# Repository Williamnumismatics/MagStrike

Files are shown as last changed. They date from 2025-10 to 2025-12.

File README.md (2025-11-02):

# MagStrike

MagStrike is a custom hall effect keyboard that has a 60 percent layout.
It uses the Gateron Low Profile Magnetic Jade Switches. The brains of this keyboard is a Rpi Pico 2 that runs micropython that communicates with a python script running on the main PC/Laptop

## Why did i build this???
I built this keyboard because i have always wanted to make my own keyboard from scratch and when i stumbled across hall-effect one day i quickly fell in love with it. I also wanted to use low profile switches so my wrists wouldnt hurt all day. I Found the perfect switch for this which is the Gateron Low Profile Magnetic Jade switches.

## What did it take?
It took about 2 weeks to build this it is my first every PCB and unfortunately i couldn't find anywhere to place the rasberry pi pico so i had to put it outside the keyboard. I also designed the case without a top plate so it is easy to print and easy to see the insides

## If i did it again what would i do?
 I would probably make a custom devboard with the rp2040 and embed it inside the footprint of the keyboard.
 
## READ THIS:
the 3d file was to big to commit to github so this is the google drive link:
    https://drive.google.com/file/d/1xGtgr9WMyzFMHPNl8FSLAcrnGV7yFdcr/view
 
### My Bill of Materials

| Item | Description | Quantity | Unit Price (USD) | Total Price (USD) | Shipping(USD) | URL | Running Total(USD) |
| :--- | :--- | :--- | :--- | :--- | :--- | :--- | :--- |
| Switches | Gateron Low Profile Magnetic Jade | 1 x pack of 70 | 56 | 56 | 4.3 | [Link](https://www.gateron.com/products/gateron-low-profile-magnetic-jade-switch?VariantsId=10872) | 60.3 |
| Stabilizer | GATERON Low Profile Plate Mounted Stabilizer | 1 | 8 | 8 | 2.45(Processing Fee) | [Link](https://www.gateron.com/products/gateron-low-profile-plate-mounted-stabilizer?VariantsId=10540) | 70.75 |
| Capacitor | 50V 100nF X7R ±10% 0603 Ceramic Capacitors RoHS | 100 | 0.0025 | 0.25 | 8.87 | [Link](https://www.lcsc.com/product-detail/C14663.html?utm_source=chatgpt.com) | 79.87 |
| Hall Effect Sensor | Analog-Bipolar Hall Effect Sensor | 70 | 0.2345 | 16.42 | N/A | [Link](https://www.lcsc.com/product-detail/C962159.html) | 96.29 |
| Multiplexer | IC MUX 16:1 160OHM 24SOIC | 5 | 0.83 | 3.32 | N/A | [Link](https://www.lcsc.com/sea rch?q=%20CD74HC4067M96%20&s_z=n_%20CD74HC4067M96%20) | 99.61 |
| Rasberry Pi Pico | Rasberry Pi Pico | 1 | 4.32 | 4.32 | 2.42 | [Link](https://core-electronics.com.au/raspberry-pi-pico.html) | 106.35 |
| PCB | THE pcb | 5 | N/A | 26.35 | 18.43 | [Link](https://cart.jlcpcb.com/shopcart/cart/) | 151.13 |

### I didnt include all of the shopping carts so here it is(Note that on gateron website it says some cheaper that the bom but that is cause of a sale that is ending in 16 hours.):
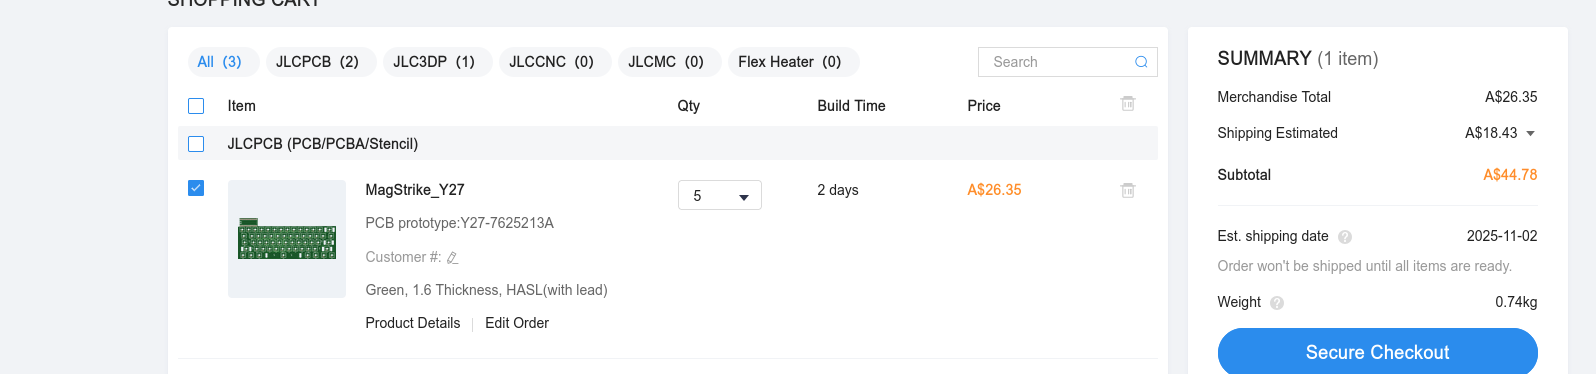
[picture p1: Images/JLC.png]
PCB

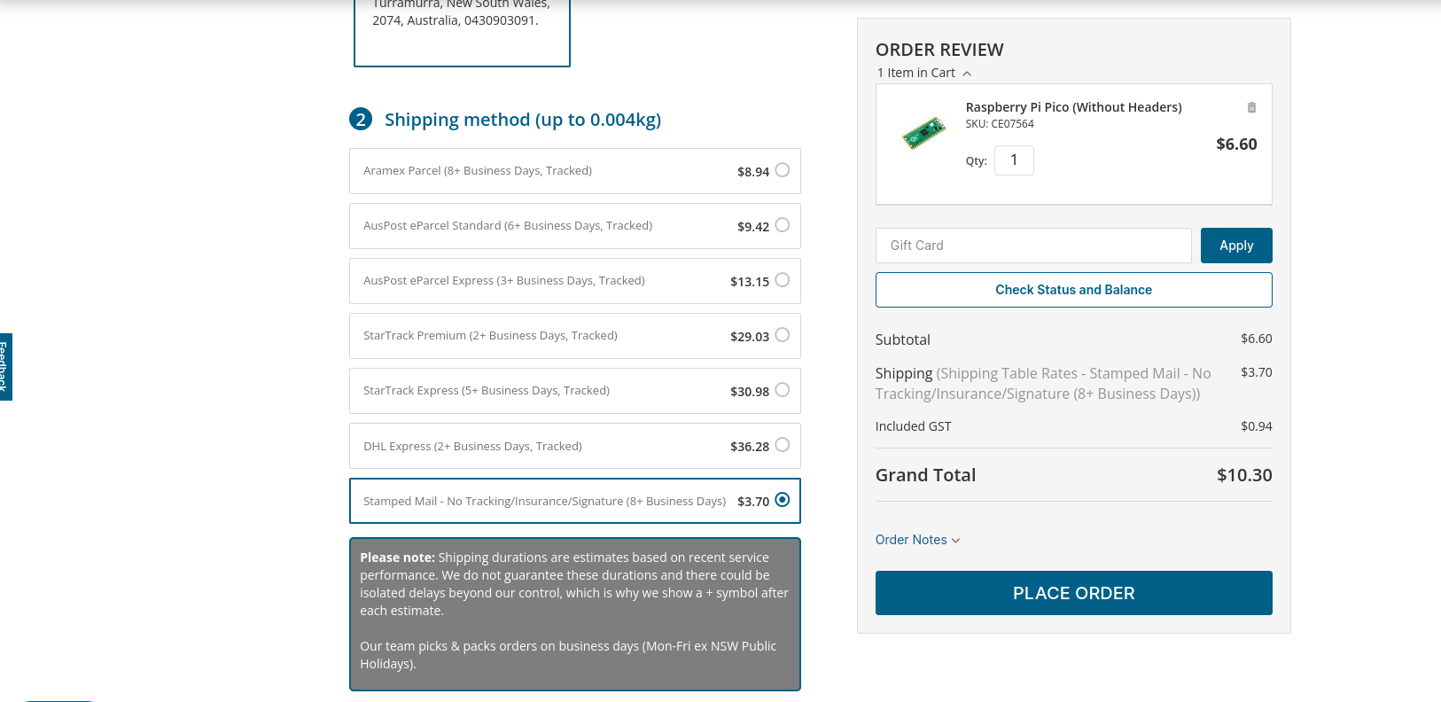
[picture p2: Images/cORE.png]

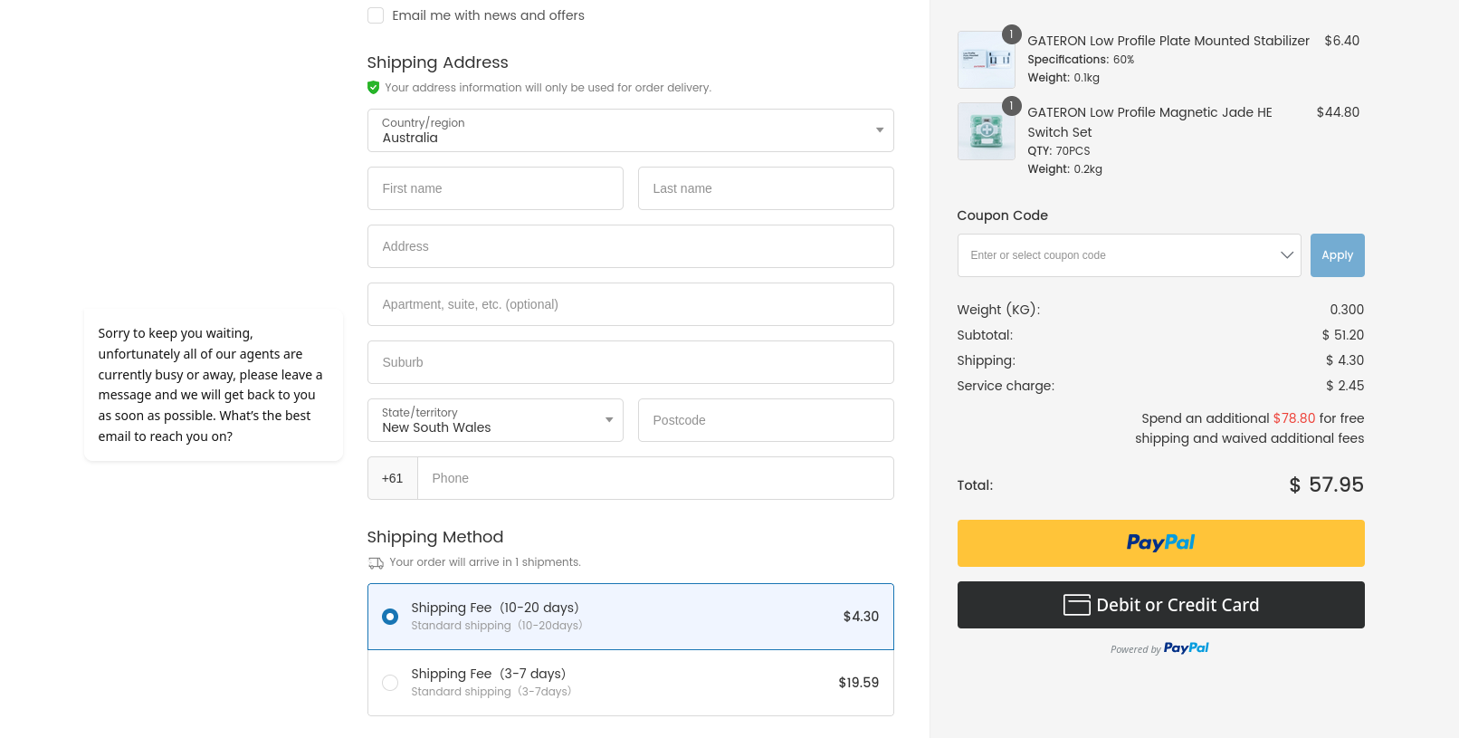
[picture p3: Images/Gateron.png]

shop
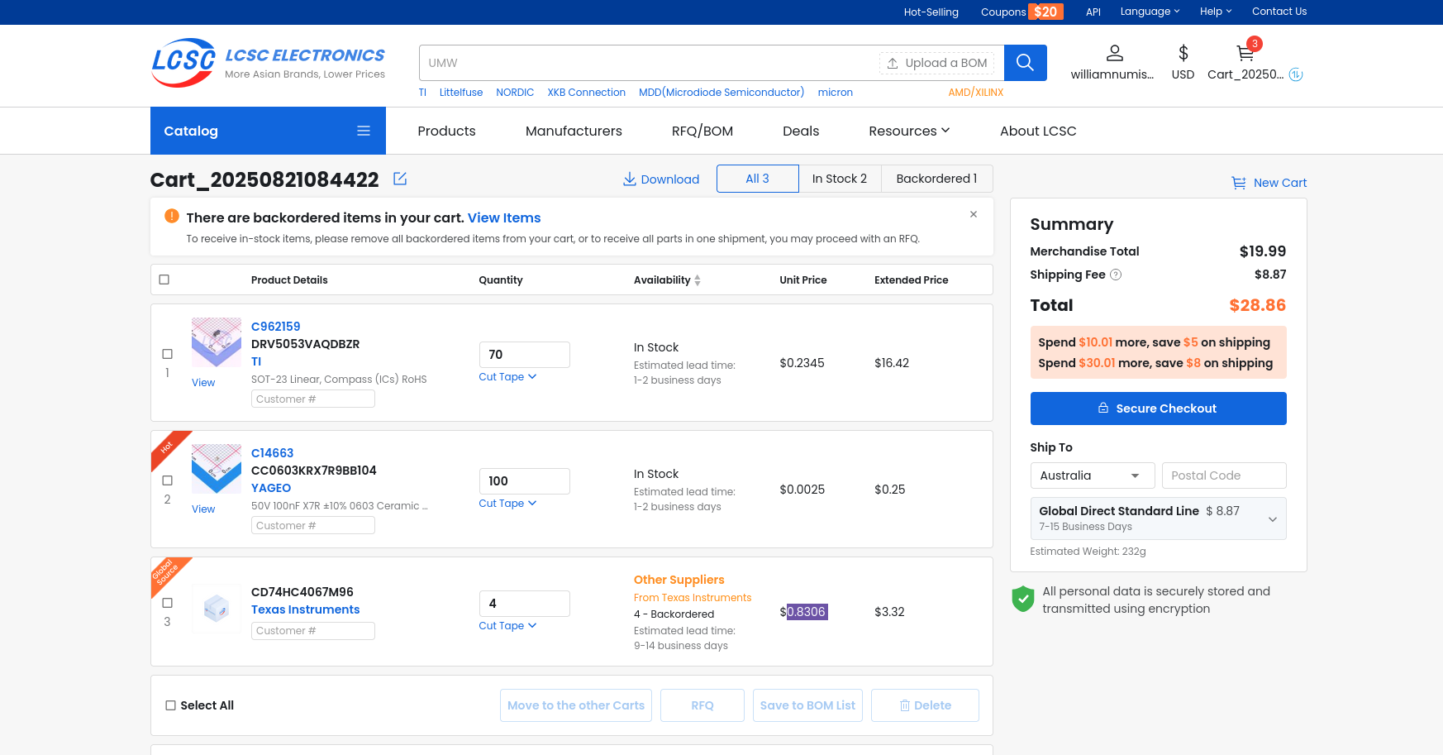
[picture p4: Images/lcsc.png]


# 3d render:
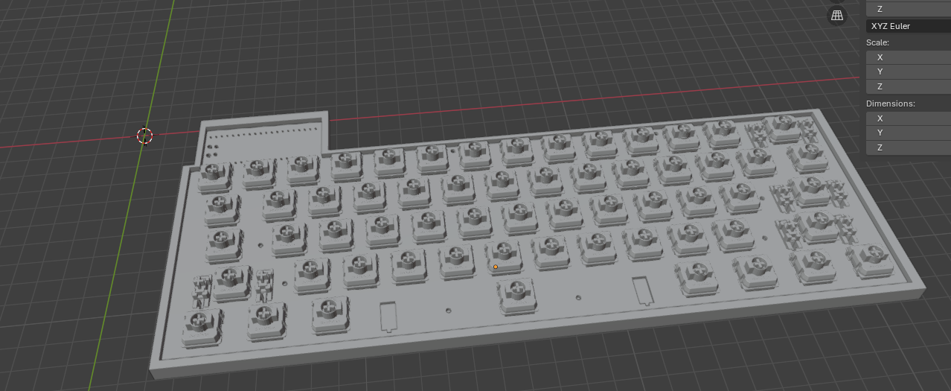
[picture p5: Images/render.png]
Render


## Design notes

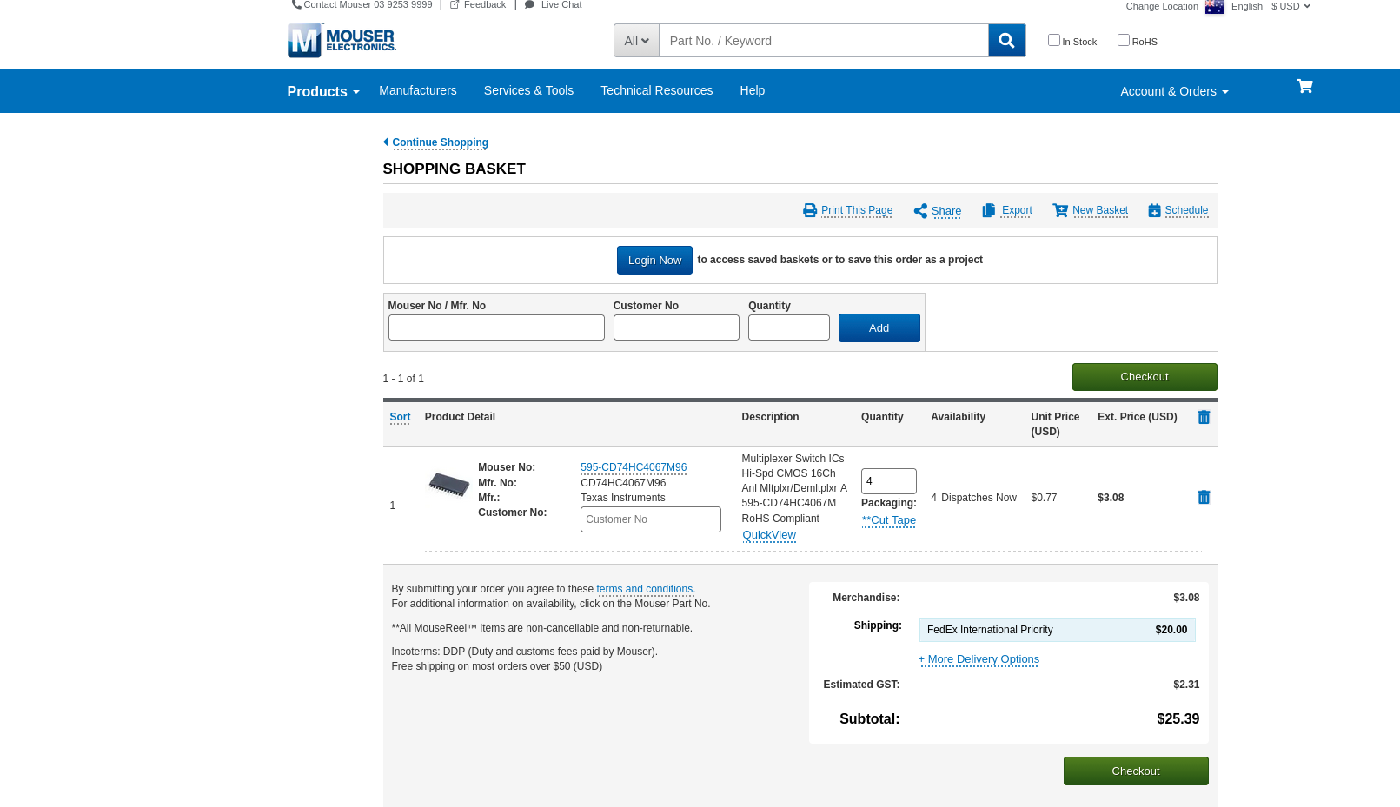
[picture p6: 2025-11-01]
Images/Mouser.png

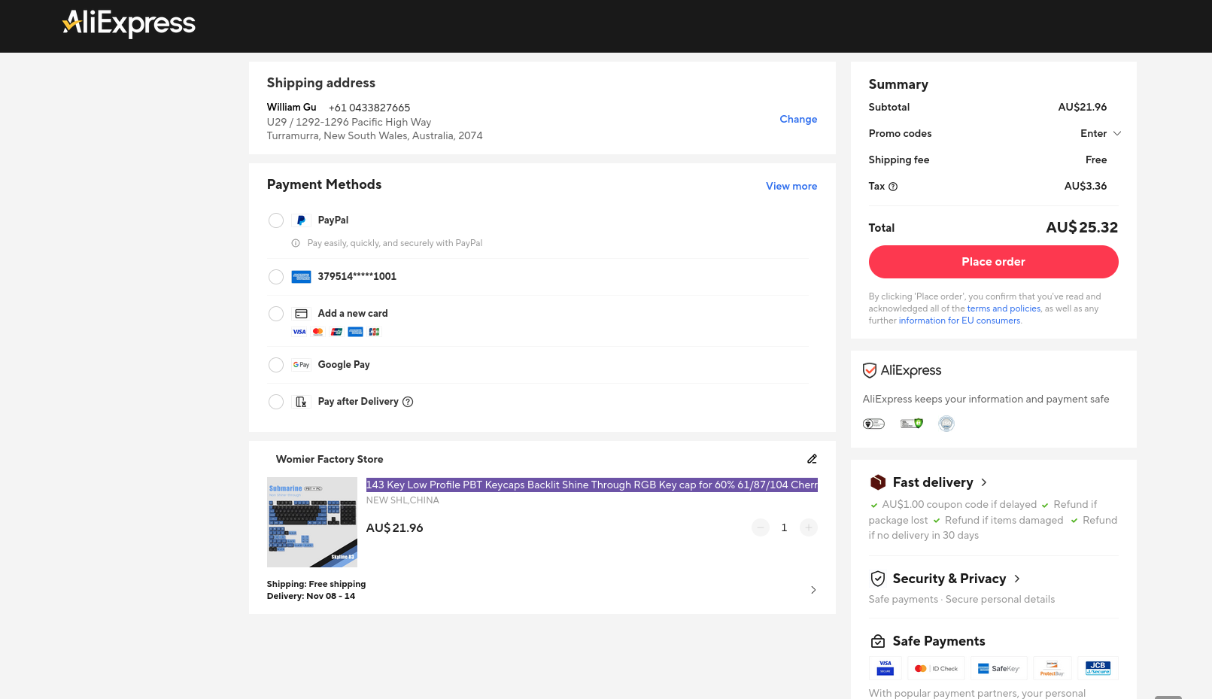
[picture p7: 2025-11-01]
Images/Ali.png

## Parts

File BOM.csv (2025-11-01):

Item | Description | Quantity | Unit Price (USD) | Total Price (USD) | Shipping(USD) | URL | Running Total(USD)
Switches | Gateron Low Profile Magnetic Jade | 1 x pack of 70 | 56 | 56 | 4.3 | https://www.gateron.com/products/gateron-low-profile-magnetic-jade-switch?VariantsId=10872 | 60.3
Stabilizer | GATERON Low Profile Plate Mounted Stabilizer | 1 | 8 | 8 | 2.45(Processing Fee) | https://www.gateron.com/products/gateron-low-profile-plate-mounted-stabilizer?VariantsId=10540 | 70.75
Capacitor | 50V 100nF X7R ±10% 0603 Ceramic Capacitors RoHS | 100 | 0.0025 | 0.25 | 8.87 | https://www.lcsc.com/product-detail/C14663.html?utm_source=chatgpt.com | 79.87
Hall Effect Sensor | Analog-Bipolar Hall Effect Sensor | 70 | 0.2345 | 16.42 | N/A | https://www.lcsc.com/product-detail/C962159.html | 96.29
Multiplexer | IC MUX 16:1 160OHM 24SOIC | 5 | 0.83 | 3.32 | N/A | https://www.lcsc.com/search?q=%2520CD74HC4067M96%2520&s_z=n_%2520CD74HC4067M96%2520 | 99.61
Rasberry Pi Pico | Rasberry Pi Pico | 1 | 4.32 | 4.32 | 2.42 | https://core-electronics.com.au/raspberry-pi-pico.html | 106.35
PCB | THE pcb | 5 | N/A | 26.35 | 18.43 | https://cart.jlcpcb.com/shopcart/cart/ | 151.13

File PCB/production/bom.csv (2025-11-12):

Designator | Footprint | Quantity | Value | LCSC Part #
A1 | RaspberryPi_Pico_Common_Unspecified | 1 | RaspberryPi_Pico
SW1, SW10, SW11, SW12, SW13, SW14, SW15, SW16, SW17, SW18, SW19, SW2, SW20, SW21, SW22, SW23, SW24, SW25, SW26, SW27, SW28, SW29, SW3, SW30, SW31, SW32, SW33, SW34, SW35, SW36, SW37, SW38, SW39, SW4, SW40, SW41, SW42, SW43, SW44, SW45, SW46, SW47, SW48, SW49, SW5, SW50, SW51, SW52, SW53, SW54, SW55, SW56, SW57, SW58, SW59, SW6, SW60, SW61, SW7, SW8, SW9 | Gateron_Low_Profile_Magnetic_Jade | 61 | ~
U1, U2, U3, U4 | SOIC-24W_7.5x15.4mm_P1.27mm | 4 | CD74HC4067M

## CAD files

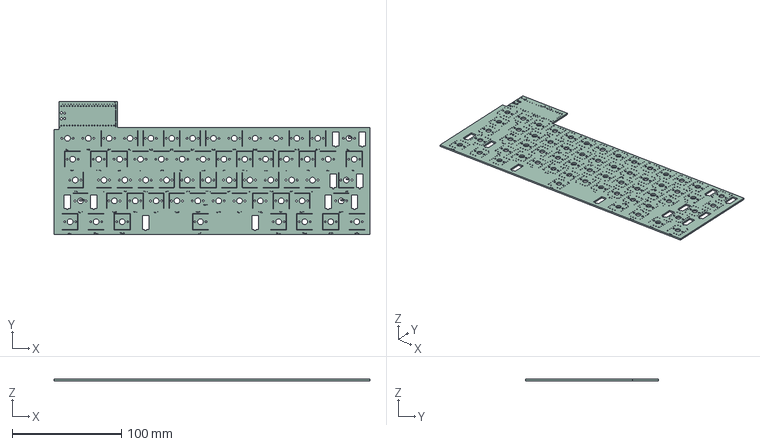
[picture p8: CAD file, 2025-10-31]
PCB/MagStrike.step
288.7 x 121.5 x 1.66 mm
MagStrike_silkscreen x 2
MagStrike_PCB

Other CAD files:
SWITCH.blend
print.blend

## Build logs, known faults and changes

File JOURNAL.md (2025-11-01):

<!--
  ===================    !!READ THIS NOTICE!!   ====================
  DO NOT edit this file manually. Your changes WILL BE OVERWRITTEN!
  This journal is auto generated and updated by Hack Club Blueprint.
  To edit this file, please edit your journal entries on Blueprint.
  ==================================================================
-->

## 10/23/2025 7 PM - Starteds on the thing and also started on the footprint  

First i started by creating the BOM and the plan file then i started on the footprint since i couldnt find any available footprint for my gateron low profile magnetic jade switch, i decided to make my own i have just done puting the sensor unter the place on the footprint next im going to move to the symbol and filling in the BOM


## 10/23/2025 8 PM - Finished Footprint  

Finished footprint for the magnetic switch was going to put per key rgb but then figured to complex as that would exeed the amp rating of the pico which would force me to use a usb PD breakotu board. Now going to do the symbol for it and then i will start on the schematic


## 10/23/2025 9 PM - doing the schematic  

finished symbol and Started doing the schematics added 61 switches 4 multiplexers and the rasberry pi pico next wil finish and then move on to pcb stuff.


## 10/24/2025 - near finish shematic  

Finished with footprint and symbol fot the switch now doingthe shematic currently wiring the 61 switches up to some analog multiplexers that go into a rasberry pi pico 


## 10/29/2025 8 PM - Finished Schematic  

Took a break and how have finished schematic will move onto the footprint next i wish myself good luck and i hope everything will turn out alright :))

## 10/29/2025 9 PM - Fixed ERC  

Ran ERC and fixed problem of the adc_vref not connecting to anything it is fixed now so tommorow i am going to move onto doing the footprints and acual pcb should be ready in about a week :)
warnings are just extra pins
 

## 10/30/2025 7 PM - Did stabilizer things  

CReated footprints for my stabilizer because i couldnt find them anywhere spent a good 30 minutes trying tho they are the gateron low profile stabilizers.

## 10/30/2025 8 PM - Started PCB  

Started PCB but ran into a problem where two components in a singular footprint was too close. Had to restart i just finished routing key 14 out of 61.

## 10/31/2025 10 AM - nearly there  

Finished Routing the switches and wil now wire up all the pins for the multiplexers. after that will work on mob and some software. Then i will ship for the first time :)Screenshot 2025-10-31 at 10.36.49 am

## 10/31/2025 2 PM - 99% done with PCB  

fINALLY FINISHED PCB ! now all i need to do i the edge cut the bom and the readme so exited to see this project come to life now !!!!!!!!! Will try finish by the end of next week :)

Screenshot 2025-10-31 at 10.36.55 am

## 10/31/2025 3 PM - Done with the PCB  

fINISHED the edge cuts but i need to put the stabilizers in but those footprints are on my PC so rn i have done everything. Wehn i get home ima gonna do the readme and bom.
Screenshot 2025-10-31 at 3.03.08 pm

## 10/31/2025 5 PM - Finished PCB :)  

Finished PCB will now write the BOM and also the readme :) Hopefully it will get approved soon. Will then do hand soldering with heatgun and also solder paste

## 10/31/2025 9 PM - Done README and BOM  

Finished Bom and README :) will ship it for review and if there is anything i can do to change, i will change. Dear Reviewer: Thanks for looking at my project :) Hope its good

## 11/1/2025 10 AM - Ok did the code  

BTW IMPOORTANT::: THIS CODE IS VIBE CODED i think it is allowed but if it isnt please ban me cause i know that it is vibe coded cause in the docs it didnt say i couldnt vibe code the firmware. ChatGPT is goated:)


## 11/1/2025 11 AM - cHANGED the BOM  

I changed the BOM and also changed the readme cause i realised in the bom my multiplexer was out of stock in LCSC so i switched to Mouser. I also relised that the price was off now and also i didnt put screenshots of my other shopping carts everything is in the README. 

### Reviewer Please Check the README!!!

## 11/1/2025 3 PM - Changed some stuff  

Reviewer said i have to cost optimize my thing so i removed the keycaps so i will 3d print them mysel;f and also changed the multiplexers from mouser to lcsc to avoid shipping.

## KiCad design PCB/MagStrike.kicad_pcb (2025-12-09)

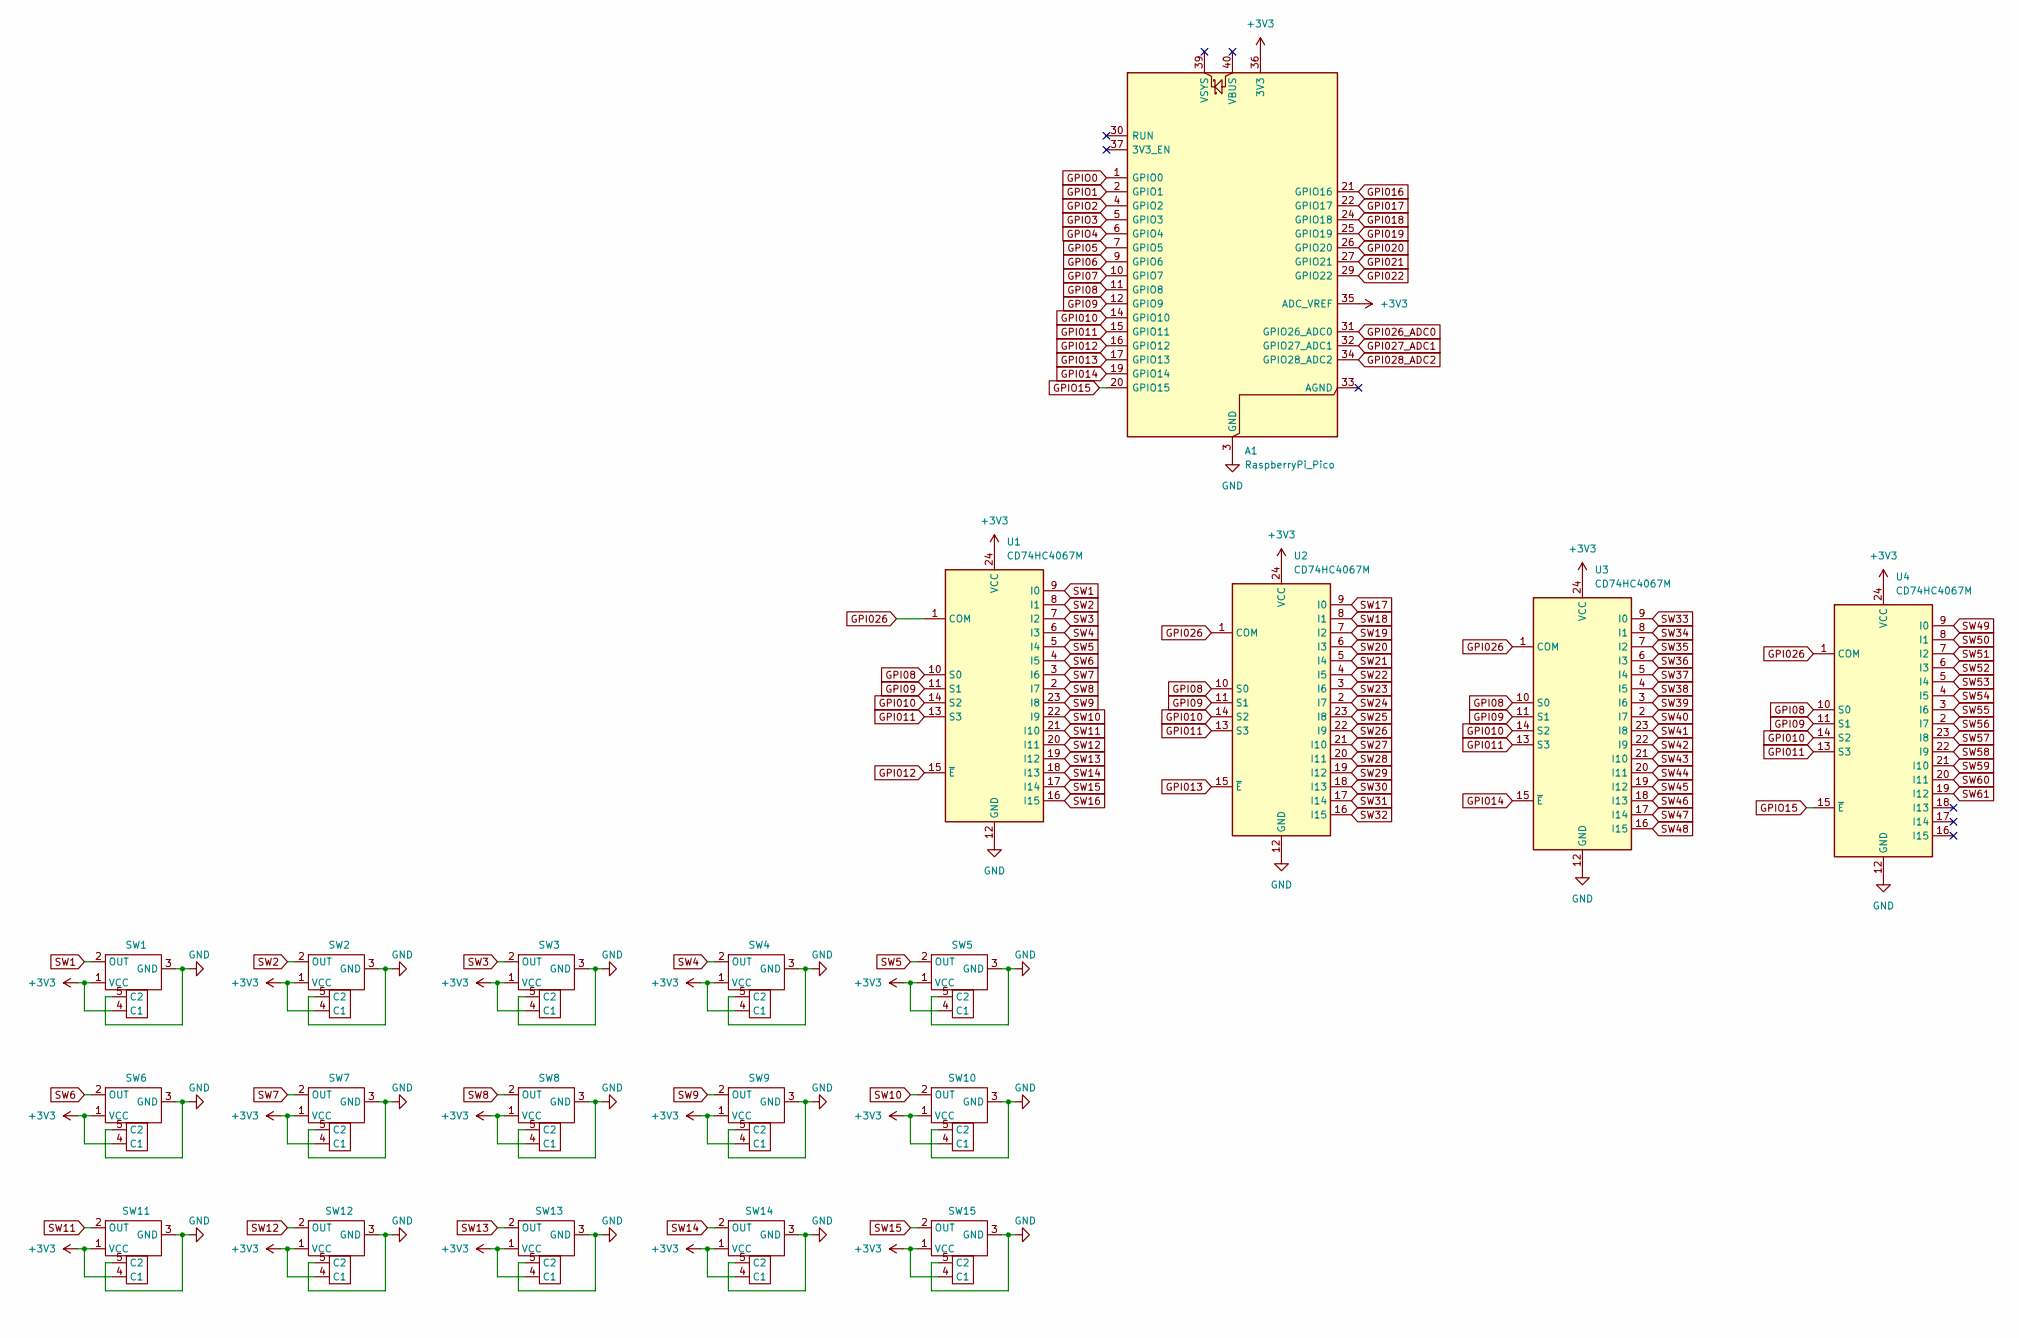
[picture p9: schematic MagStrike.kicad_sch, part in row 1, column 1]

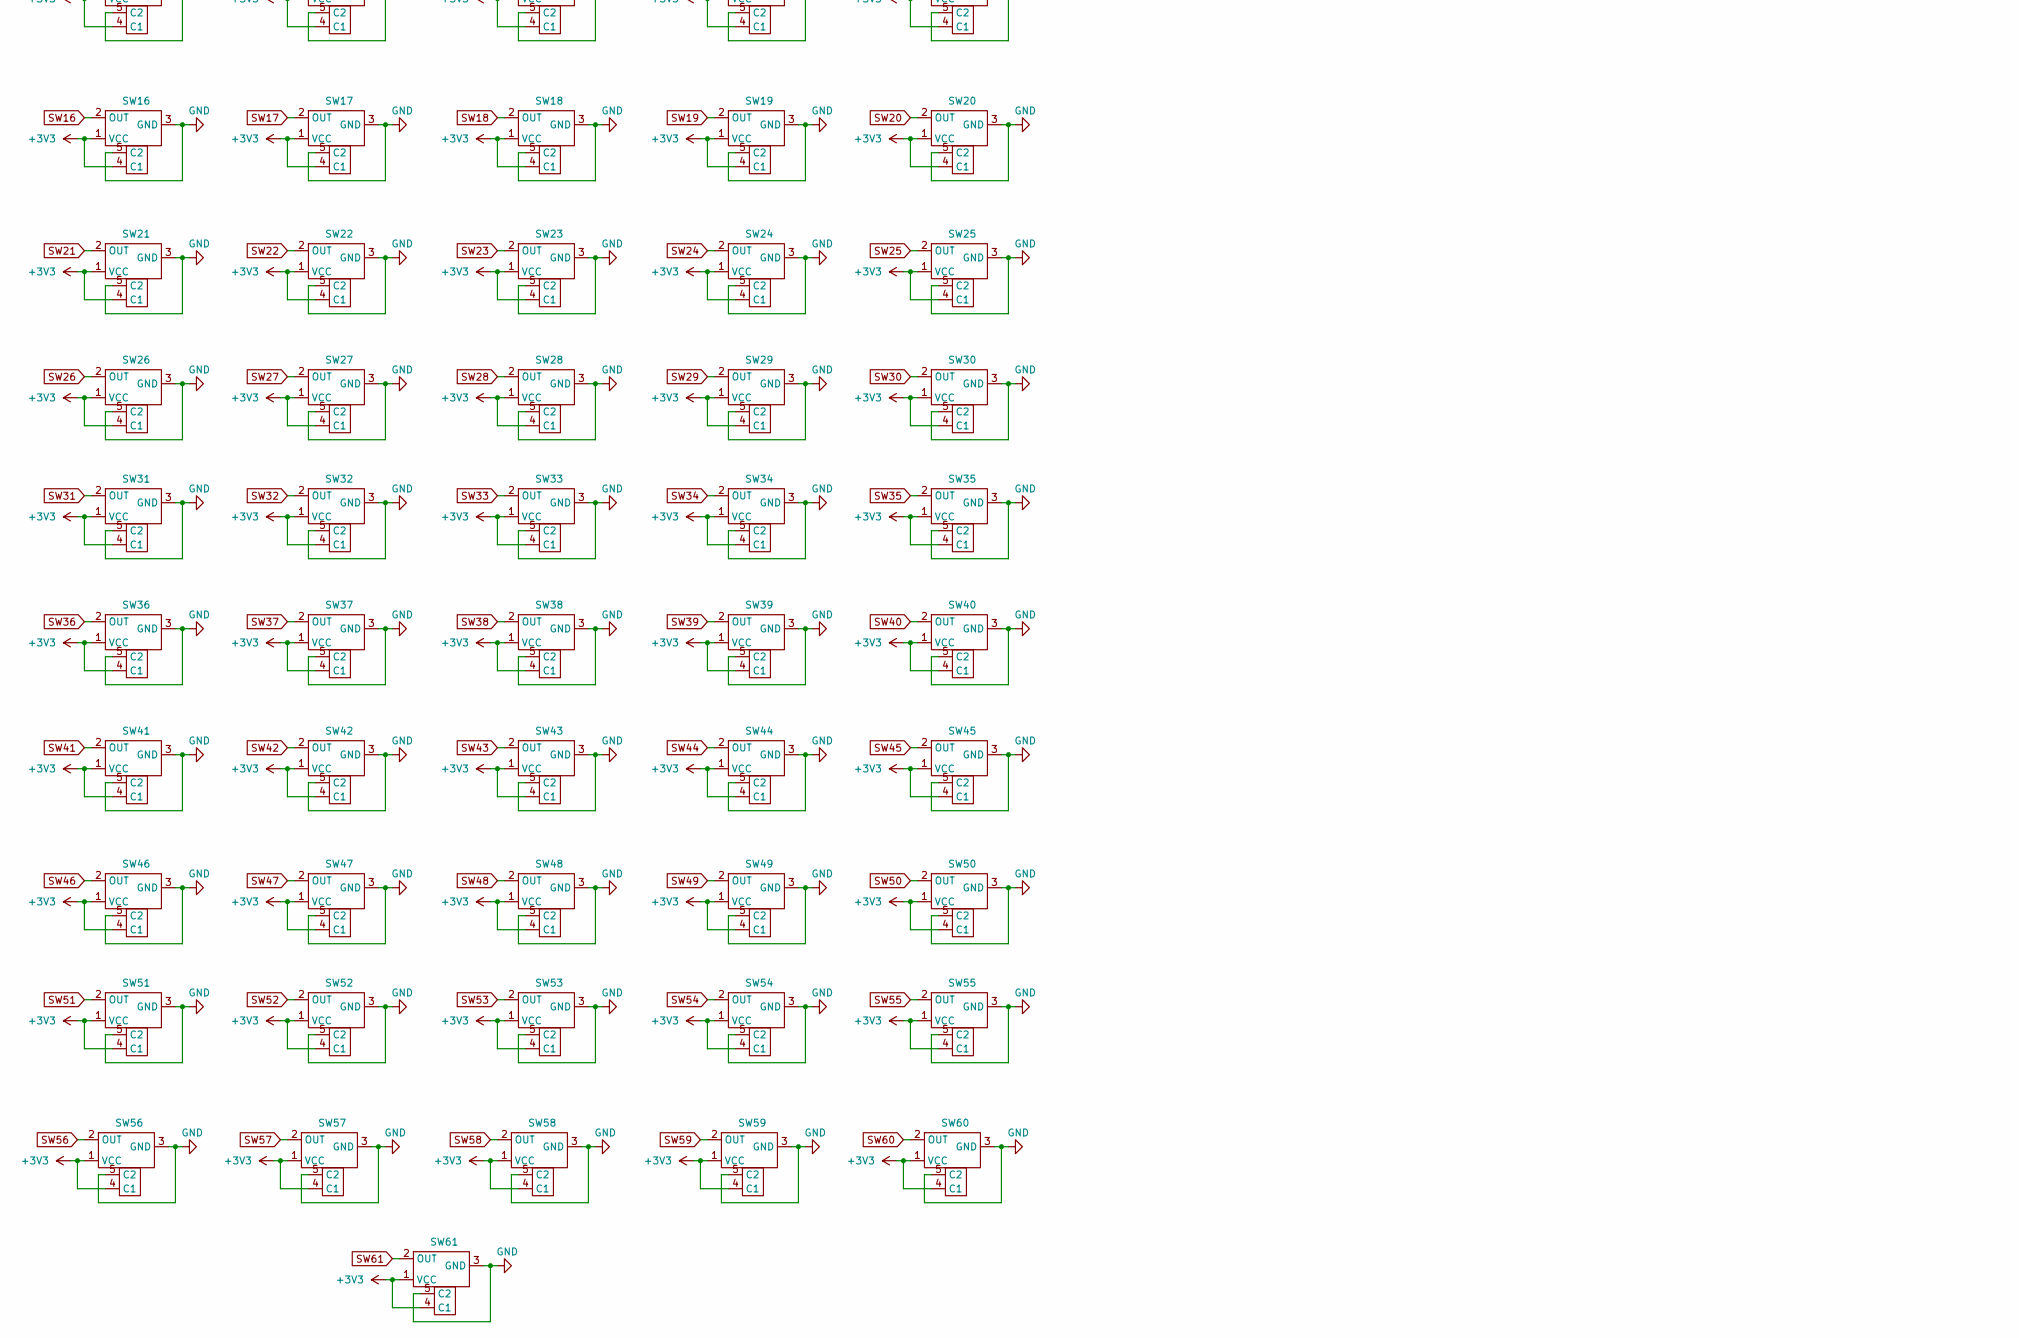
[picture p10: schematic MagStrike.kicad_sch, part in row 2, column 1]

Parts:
A1: RaspberryPi_Pico; RaspberryPi_Pico_Common_Unspecified
SW1, SW2, SW3, SW4, SW5, SW6, SW7, SW8, SW9, SW10, SW11, SW12, SW13, SW14, SW15, SW16, SW17, SW18, SW19, SW20, SW21, SW22, SW23, SW24, SW25, SW26, SW27, SW28, SW29, SW30, SW31, SW32, SW33, SW34, SW35, SW36, SW37, SW38, SW39, SW40, SW41, SW42, SW43, SW44, SW45, SW46, SW47, SW48, SW49, SW50, SW51, SW52, SW53, SW54, SW55, SW56, SW57, SW58, SW59, SW60, SW61: Gateron_Low_Profile_Magnetic_Jade
U1, U2, U3, U4: CD74HC4067M; SOIC-24W_7.5x15.4mm_P1.27mm

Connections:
+3V3: A1.35 (ADC_VREF), A1.36 (3V3), SW1.1 (VCC), SW1.4 (C1), SW2.1 (VCC), SW2.4 (C1), SW3.1 (VCC), SW3.4 (C1), SW4.1 (VCC), SW4.4 (C1), SW5.1 (VCC), SW5.4 (C1), SW6.1 (VCC), SW6.4 (C1), SW7.1 (VCC), SW7.4 (C1), SW8.1 (VCC), SW8.4 (C1), SW9.1 (VCC), SW9.4 (C1), SW10.1 (VCC), SW10.4 (C1), SW11.1 (VCC), SW11.4 (C1), SW12.1 (VCC), SW12.4 (C1), SW13.1 (VCC), SW13.4 (C1), SW14.1 (VCC), SW14.4 (C1), SW15.1 (VCC), SW15.4 (C1), SW16.1 (VCC), SW16.4 (C1), SW17.1 (VCC), SW17.4 (C1), SW18.1 (VCC), SW18.4 (C1), SW19.1 (VCC), SW19.4 (C1), SW20.1 (VCC), SW20.4 (C1), SW21.1 (VCC), SW21.4 (C1), SW22.1 (VCC), SW22.4 (C1), SW23.1 (VCC), SW23.4 (C1), SW24.1 (VCC), SW24.4 (C1), SW25.1 (VCC), SW25.4 (C1), SW26.1 (VCC), SW26.4 (C1), SW27.1 (VCC), SW27.4 (C1), SW28.1 (VCC), SW28.4 (C1), SW29.1 (VCC), SW29.4 (C1), SW30.1 (VCC), SW30.4 (C1), SW31.1 (VCC), SW31.4 (C1), SW32.1 (VCC), SW32.4 (C1), SW33.1 (VCC), SW33.4 (C1), SW34.1 (VCC), SW34.4 (C1), SW35.1 (VCC), SW35.4 (C1), SW36.1 (VCC), SW36.4 (C1), SW37.1 (VCC), SW37.4 (C1), SW38.1 (VCC), SW38.4 (C1), SW39.1 (VCC), SW39.4 (C1), SW40.1 (VCC), SW40.4 (C1), SW41.1 (VCC), SW41.4 (C1), SW42.1 (VCC), SW42.4 (C1), SW43.1 (VCC), SW43.4 (C1), SW44.1 (VCC), SW44.4 (C1), SW45.1 (VCC), SW45.4 (C1), SW46.1 (VCC), SW46.4 (C1), SW47.1 (VCC), SW47.4 (C1), SW48.1 (VCC), SW48.4 (C1), SW49.1 (VCC), SW49.4 (C1), SW50.1 (VCC), SW50.4 (C1), SW51.1 (VCC), SW51.4 (C1), SW52.1 (VCC), SW52.4 (C1), SW53.1 (VCC), SW53.4 (C1), SW54.1 (VCC), SW54.4 (C1), SW55.1 (VCC), SW55.4 (C1), SW56.1 (VCC), SW56.4 (C1), SW57.1 (VCC), SW57.4 (C1), SW58.1 (VCC), SW58.4 (C1), SW59.1 (VCC), SW59.4 (C1), SW60.1 (VCC), SW60.4 (C1), SW61.1 (VCC), SW61.4 (C1), U1.24 (VCC), U2.24 (VCC), U3.24 (VCC), U4.24 (VCC)
GND: A1.3 (GND), A1.8 (GND), A1.13 (GND), A1.18 (GND), A1.23 (GND), A1.28 (GND), A1.38 (GND), SW1.3 (GND), SW1.5 (C2), SW2.3 (GND), SW2.5 (C2), SW3.3 (GND), SW3.5 (C2), SW4.3 (GND), SW4.5 (C2), SW5.3 (GND), SW5.5 (C2), SW6.3 (GND), SW6.5 (C2), SW7.3 (GND), SW7.5 (C2), SW8.3 (GND), SW8.5 (C2), SW9.3 (GND), SW9.5 (C2), SW10.3 (GND), SW10.5 (C2), SW11.3 (GND), SW11.5 (C2), SW12.3 (GND), SW12.5 (C2), SW13.3 (GND), SW13.5 (C2), SW14.3 (GND), SW14.5 (C2), SW15.3 (GND), SW15.5 (C2), SW16.3 (GND), SW16.5 (C2), SW17.3 (GND), SW17.5 (C2), SW18.3 (GND), SW18.5 (C2), SW19.3 (GND), SW19.5 (C2), SW20.3 (GND), SW20.5 (C2), SW21.3 (GND), SW21.5 (C2), SW22.3 (GND), SW22.5 (C2), SW23.3 (GND), SW23.5 (C2), SW24.3 (GND), SW24.5 (C2), SW25.3 (GND), SW25.5 (C2), SW26.3 (GND), SW26.5 (C2), SW27.3 (GND), SW27.5 (C2), SW28.3 (GND), SW28.5 (C2), SW29.3 (GND), SW29.5 (C2), SW30.3 (GND), SW30.5 (C2), SW31.3 (GND), SW31.5 (C2), SW32.3 (GND), SW32.5 (C2), SW33.3 (GND), SW33.5 (C2), SW34.3 (GND), SW34.5 (C2), SW35.3 (GND), SW35.5 (C2), SW36.3 (GND), SW36.5 (C2), SW37.3 (GND), SW37.5 (C2), SW38.3 (GND), SW38.5 (C2), SW39.3 (GND), SW39.5 (C2), SW40.3 (GND), SW40.5 (C2), SW41.3 (GND), SW41.5 (C2), SW42.3 (GND), SW42.5 (C2), SW43.3 (GND), SW43.5 (C2), SW44.3 (GND), SW44.5 (C2), SW45.3 (GND), SW45.5 (C2), SW46.3 (GND), SW46.5 (C2), SW47.3 (GND), SW47.5 (C2), SW48.3 (GND), SW48.5 (C2), SW49.3 (GND), SW49.5 (C2), SW50.3 (GND), SW50.5 (C2), SW51.3 (GND), SW51.5 (C2), SW52.3 (GND), SW52.5 (C2), SW53.3 (GND), SW53.5 (C2), SW54.3 (GND), SW54.5 (C2), SW55.3 (GND), SW55.5 (C2), SW56.3 (GND), SW56.5 (C2), SW57.3 (GND), SW57.5 (C2), SW58.3 (GND), SW58.5 (C2), SW59.3 (GND), SW59.5 (C2), SW60.3 (GND), SW60.5 (C2), SW61.3 (GND), SW61.5 (C2), U1.12 (GND), U2.12 (GND), U3.12 (GND), U4.12 (GND)
GPI05: A1.7 (GPIO5)
GPI06: A1.9 (GPIO6)
GPI07: A1.10 (GPIO7)
GPI08: A1.11 (GPIO8), U1.10 (S0), U2.10 (S0), U3.10 (S0), U4.10 (S0)
GPI09: A1.12 (GPIO9), U1.11 (S1), U2.11 (S1), U3.11 (S1), U4.11 (S1)
GPI010: A1.14 (GPIO10), U1.14 (S2), U2.14 (S2), U3.14 (S2), U4.14 (S2)
GPI011: A1.15 (GPIO11), U1.13 (S3), U2.13 (S3), U3.13 (S3), U4.13 (S3)
GPI012: A1.16 (GPIO12), U1.15 (~E)
GPI013: A1.17 (GPIO13), U2.15 (~E)
GPI014: A1.19 (GPIO14), U3.15 (~E)
GPI016: A1.21 (GPIO16)
GPI017: A1.22 (GPIO17)
GPI018: A1.24 (GPIO18)
GPI019: A1.25 (GPIO19)
GPI020: A1.26 (GPIO20)
GPI021: A1.27 (GPIO21)
GPI022: A1.29 (GPIO22)
GPI026: U1.1 (COM), U2.1 (COM), U3.1 (COM), U4.1 (COM)
GPI026_ADC0: A1.31 (GPIO26_ADC0)
GPI027_ADC1: A1.32 (GPIO27_ADC1)
GPI028_ADC2: A1.34 (GPIO28_ADC2)
GPIO0: A1.1 (GPIO0)
GPIO1: A1.2 (GPIO1)
GPIO2: A1.4 (GPIO2)
GPIO3: A1.5 (GPIO3)
GPIO4: A1.6 (GPIO4)
GPIO15: A1.20 (GPIO15), U4.15 (~E)
SW1: SW1.2 (OUT), U1.9 (I0)
SW2: SW2.2 (OUT), U1.8 (I1)
SW3: SW3.2 (OUT), U1.7 (I2)
SW4: SW4.2 (OUT), U1.6 (I3)
SW5: SW5.2 (OUT), U1.5 (I4)
SW6: SW6.2 (OUT), U1.4 (I5)
SW7: SW7.2 (OUT), U1.3 (I6)
SW8: SW8.2 (OUT), U1.2 (I7)
SW9: SW9.2 (OUT), U1.23 (I8)
SW10: SW10.2 (OUT), U1.22 (I9)
SW11: SW11.2 (OUT), U1.21 (I10)
SW12: SW12.2 (OUT), U1.20 (I11)
SW13: SW13.2 (OUT), U1.19 (I12)
SW14: SW14.2 (OUT), U1.18 (I13)
SW15: SW15.2 (OUT), U1.17 (I14)
SW16: SW16.2 (OUT), U1.16 (I15)
SW17: SW17.2 (OUT), U2.9 (I0)
SW18: SW18.2 (OUT), U2.8 (I1)
SW19: SW19.2 (OUT), U2.7 (I2)
SW20: SW20.2 (OUT), U2.6 (I3)
SW21: SW21.2 (OUT), U2.5 (I4)
SW22: SW22.2 (OUT), U2.4 (I5)
SW23: SW23.2 (OUT), U2.3 (I6)
SW24: SW24.2 (OUT), U2.2 (I7)
SW25: SW25.2 (OUT), U2.23 (I8)
SW26: SW26.2 (OUT), U2.22 (I9)
SW27: SW27.2 (OUT), U2.21 (I10)
SW28: SW28.2 (OUT), U2.20 (I11)
SW29: SW29.2 (OUT), U2.19 (I12)
SW30: SW30.2 (OUT), U2.18 (I13)
SW31: SW31.2 (OUT), U2.17 (I14)
SW32: SW32.2 (OUT), U2.16 (I15)
SW33: SW33.2 (OUT), U3.9 (I0)
SW34: SW34.2 (OUT), U3.8 (I1)
SW35: SW35.2 (OUT), U3.7 (I2)
SW36: SW36.2 (OUT), U3.6 (I3)
SW37: SW37.2 (OUT), U3.5 (I4)
SW38: SW38.2 (OUT), U3.4 (I5)
SW39: SW39.2 (OUT), U3.3 (I6)
SW40: SW40.2 (OUT), U3.2 (I7)
SW41: SW41.2 (OUT), U3.23 (I8)
SW42: SW42.2 (OUT), U3.22 (I9)
SW43: SW43.2 (OUT), U3.21 (I10)
SW44: SW44.2 (OUT), U3.20 (I11)
SW45: SW45.2 (OUT), U3.19 (I12)
SW46: SW46.2 (OUT), U3.18 (I13)
SW47: SW47.2 (OUT), U3.17 (I14)
SW48: SW48.2 (OUT), U3.16 (I15)
SW49: SW49.2 (OUT), U4.9 (I0)
SW50: SW50.2 (OUT), U4.8 (I1)
SW51: SW51.2 (OUT), U4.7 (I2)
SW52: SW52.2 (OUT), U4.6 (I3)
SW53: SW53.2 (OUT), U4.5 (I4)
SW54: SW54.2 (OUT), U4.4 (I5)
SW55: SW55.2 (OUT), U4.3 (I6)
SW56: SW56.2 (OUT), U4.2 (I7)
SW57: SW57.2 (OUT), U4.23 (I8)
SW58: SW58.2 (OUT), U4.22 (I9)
SW59: SW59.2 (OUT), U4.21 (I10)
SW60: SW60.2 (OUT), U4.20 (I11)
SW61: SW61.2 (OUT), U4.19 (I12)

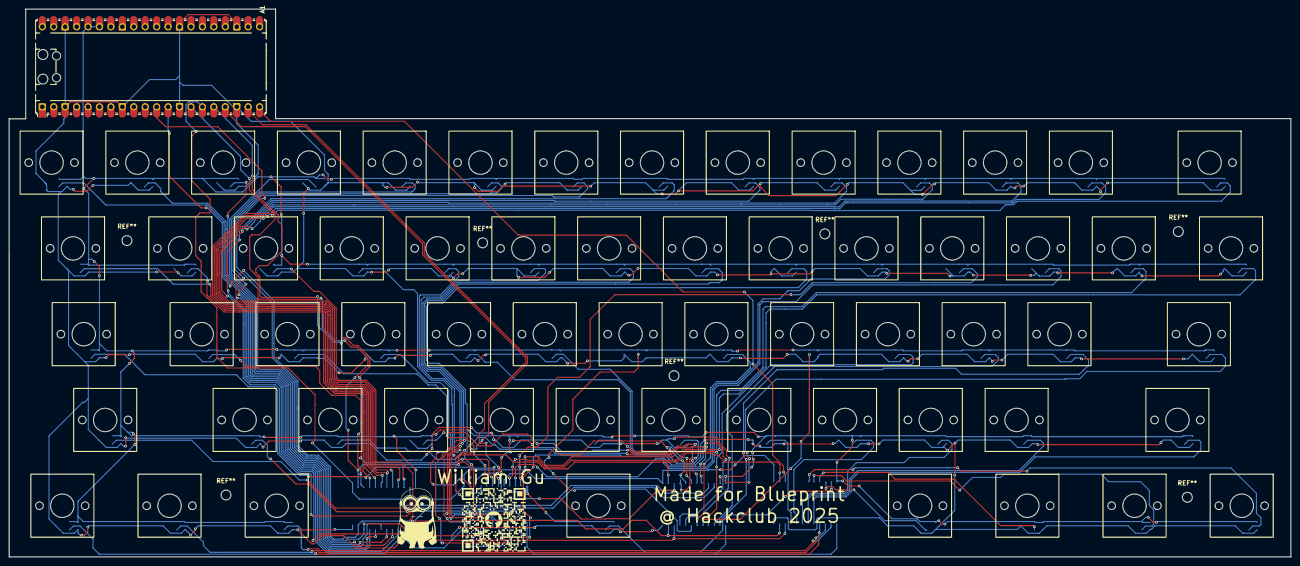
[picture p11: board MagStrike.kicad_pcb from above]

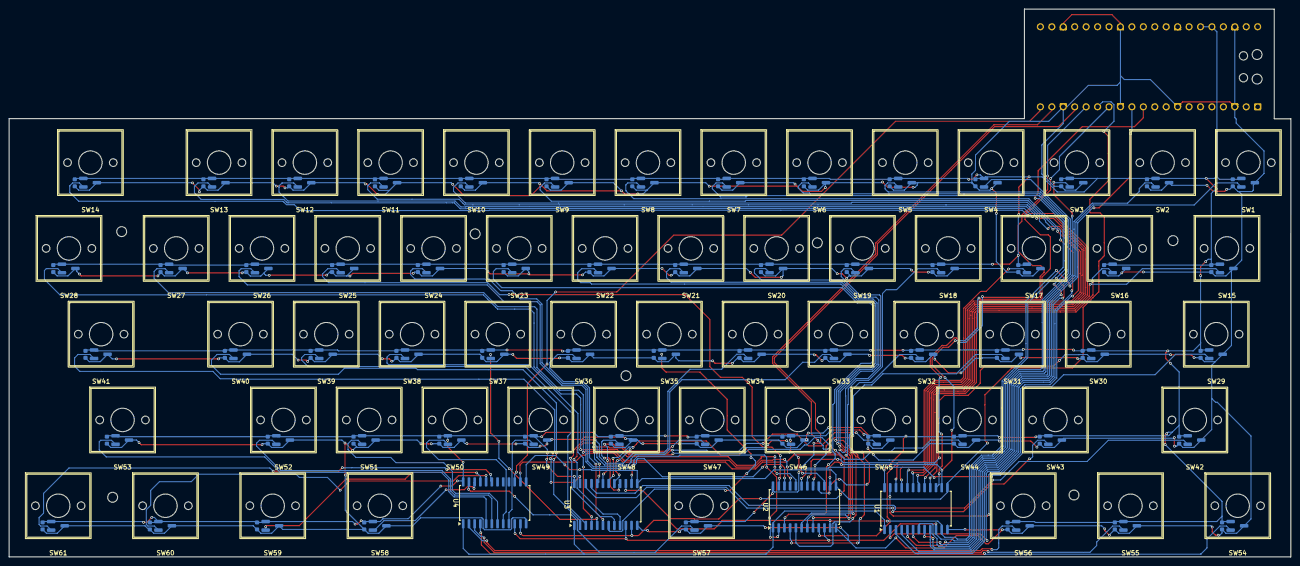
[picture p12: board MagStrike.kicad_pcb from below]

Board: 2 copper layers, 284.7 x 121.7 mm, 66 parts (65 on the bottom side), 72 nets.

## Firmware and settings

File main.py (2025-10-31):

# hall_keyboard_scan.py
# MicroPython for Raspberry Pi Pico
# 4x CD74HC4067 multiplexers with 61 analog Hall sensors
# Shared select pins (GP8–GP11), shared ADC (GP26), individual enable pins (GP12–GP15)

from machine import Pin, ADC
import time

# ---- CONFIG ----
SELECT_PINS = [8, 9, 10, 11]       # S0..S3
ENABLE_PINS = [12, 13, 14, 15]     # MUX0..MUX3 EN pins (active LOW)
ADC_PIN = 26                       # Common analog read pin

TOTAL_SENSORS = 61
CH_PER_MUX = 16
THRESHOLD_PERCENT = 10.0           # 10% magnetic increase = pressed
# -----------------

# Setup pins
selects = [Pin(p, Pin.OUT) for p in SELECT_PINS]
enables = [Pin(p, Pin.OUT) for p in ENABLE_PINS]
adc = ADC(ADC_PIN)

def set_mux_enabled(mux_index, enabled):
    # Active LOW
    enables[mux_index].value(0 if enabled else 1)

def set_channel(ch):
    for i, pin in enumerate(selects):
        pin.value((ch >> i) & 1)

def disable_all_muxes():
    for i in range(len(enables)):
        enables[i].value(1)

def read_adc():
    return adc.read_u16()

def sensor_to_mux_chan(sensor_idx):
    mux = sensor_idx // CH_PER_MUX
    ch = sensor_idx % CH_PER_MUX
    return mux, ch

# --- Calibration ---
def calibrate(samples=30):
    print("Calibrating... Keep magnets away.")
    baseline = [0]*TOTAL_SENSORS
    for _ in range(samples):
        for s in range(TOTAL_SENSORS):
            mux, ch = sensor_to_mux_chan(s)
            disable_all_muxes()
            set_mux_enabled(mux, True)
            set_channel(ch)
            time.sleep_us(500)
            baseline[s] += read_adc()
        time.sleep_ms(5)
    baseline = [b//samples for b in baseline]
    print("Calibration done.")
    return baseline

# --- Main Loop ---
def main():
    baseline = calibrate()
    pressed = [False]*TOTAL_SENSORS
    disable_all_muxes()
    print("Scanning...")

    while True:
        for s in range(TOTAL_SENSORS):
            mux, ch = sensor_to_mux_chan(s)
            disable_all_muxes()
            set_mux_enabled(mux, True)
            set_channel(ch)
            time.sleep_us(300)
            val = read_adc()
            disable_all_muxes()

            # Percent relative to baseline
            diff = val - baseline[s]
            pct = (diff / 65535) * 100
            if pct >= THRESHOLD_PERCENT and not pressed[s]:
                pressed[s] = True
                print("Key", s, "pressed")
            elif pct < (THRESHOLD_PERCENT / 2) and pressed[s]:
                pressed[s] = False
                print("Key", s, "released")
        time.sleep_ms(10)

main()

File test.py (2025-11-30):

import serial
import matplotlib.pyplot as plt
from collections import deque

# Set the correct COM port and baud rate
# On Windows: 'COM3', 'COM4', etc.
# On Linux/macOS: '/dev/ttyACM0' or '/dev/ttyUSB0'
ser = serial.Serial('/dev/ttyACM0', 115200, timeout=1)

# Prepare plot
plt.ion()  # interactive mode
fig, ax = plt.subplots()
window_size = 100
data = deque([0]*window_size, maxlen=window_size)
line, = ax.plot(range(window_size), data)
ax.set_ylim(0, 65535)  # ADC range

while True:
    try:
        line_str = ser.readline().decode('utf-8').strip()
        if line_str:
            val = int(line_str)
            data.append(val)
            line.set_ydata(data)
            plt.pause(0.01)
    except KeyboardInterrupt:
        break
    except Exception as e:
        print(e)

ser.close()

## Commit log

2025-10-23 Created files
    Created BOM and Plan files
2025-10-23 Created PCB files
    [MagStrike.kicad_pcb, MagStrike.kicad_sch]
2025-10-23 added lots of kicad stuff
    [BOM.csv, MagStrike.kicad_sch]
2025-10-24 added stuff
    [BOM.csv, MagStrike.kicad_sch]
2025-10-30 more stuff
    [MagStrike.kicad_pcb, MagStrike.kicad_sch, freerouting.dsn]
2025-10-31 a
    Former-commit-id: 5bc5bd5ef2ed26bd0dc48ccef968d0766c1999c1
    [MagStrike.kicad_pcb, MagStrike.step]
2025-11-09 sad
    me is dum i just figured out that in the specs my switch requres the sensor to be on the borrom and i put them in the top welp ima gonna start the pcb over :(
    [MagStrike.kicad_pcb, SWITCH.blend, print.blend]
2025-11-09 aaa
    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
    [MagStrike.kicad_pcb]
2025-11-10 t
    f
    [MagStrike.kicad_pcb]
2025-11-10 alnm sdklnsdjklsdf
    more traces 👍
    [MagStrike.kicad_pcb]
2025-11-11 more traces
    more traces
    [MagStrike.kicad_pcb]
2025-11-11 yieee
    finished hopefully
    [MagStrike.kicad_pcb]
2025-11-12 finilization
    I hope this is the final one
    [MagStrike.kicad_pcb, bom.csv, designators.csv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]
2025-11-12 more
    stuff just silkscreen now tho
2025-11-12 mr
    r
    [MagStrike.kicad_pcb]
2025-11-12 more refining
    more refining
    [MagStrike.kicad_pcb]
2025-11-13 more stuff
    more silkscreening
    [MagStrike.kicad_pcb]
2025-11-13 fixed drc issues
    [MagStrike.kicad_pcb]
2025-12-01 some sad things
    i have my pcb but relised i have done the pinout wrong
    [MagStrike.kicad_pcb, MagStrike.kicad_sch]
2025-12-04 more stuff
    mores stutff
    [MagStrike.kicad_pcb, MagStrike.kicad_sch]
2025-12-08 push final 1.2
    This is the mabe final version for my thing it should be done i will do some final checks tho
    [MagStrike.kicad_pcb]
2025-12-08 final stuff with silkscreen
    [MagStrike.kicad_pcb]
2025-12-09 idk what i did
    [MagStrike.kicad_pcb]
2025-12-09 added a step file
    [MagStrike.kicad_pcb]
